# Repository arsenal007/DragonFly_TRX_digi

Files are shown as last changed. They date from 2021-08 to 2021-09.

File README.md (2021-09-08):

# DragonFly_TRX_digi
DragonFly 7Mhz HF transceiver for DIGITAL Modes

Assambly:
 1) Band pass filter
 2) QER Crystal filter
 3) MCU VFO part, first of all RX/TX for RX and TX path power supplay
  3.1 also VFO/BFO is important, using frequency counter to calibrate. BFO use 2µA
  
 4) Q1/Q6 setup current about 20mA
 5) mount 78L06(U13) and mixer, check voltage
 6)

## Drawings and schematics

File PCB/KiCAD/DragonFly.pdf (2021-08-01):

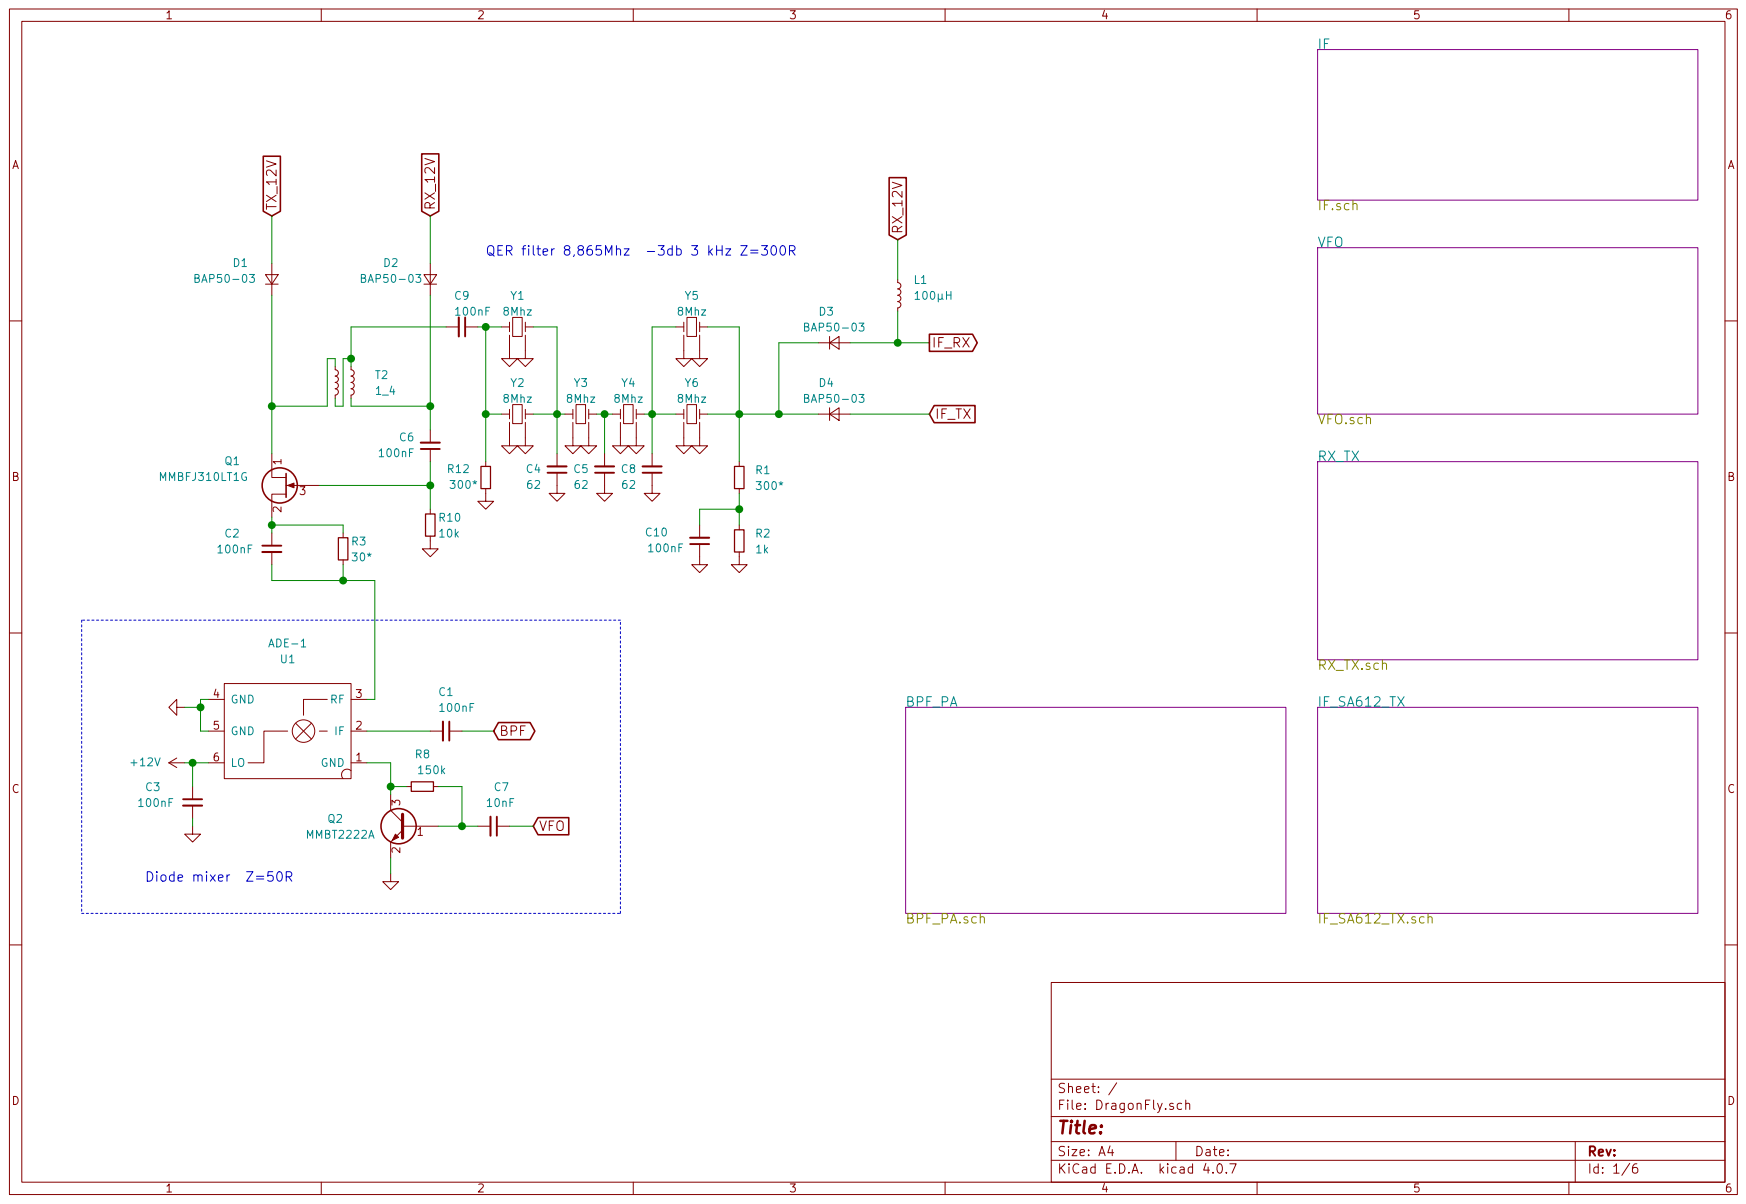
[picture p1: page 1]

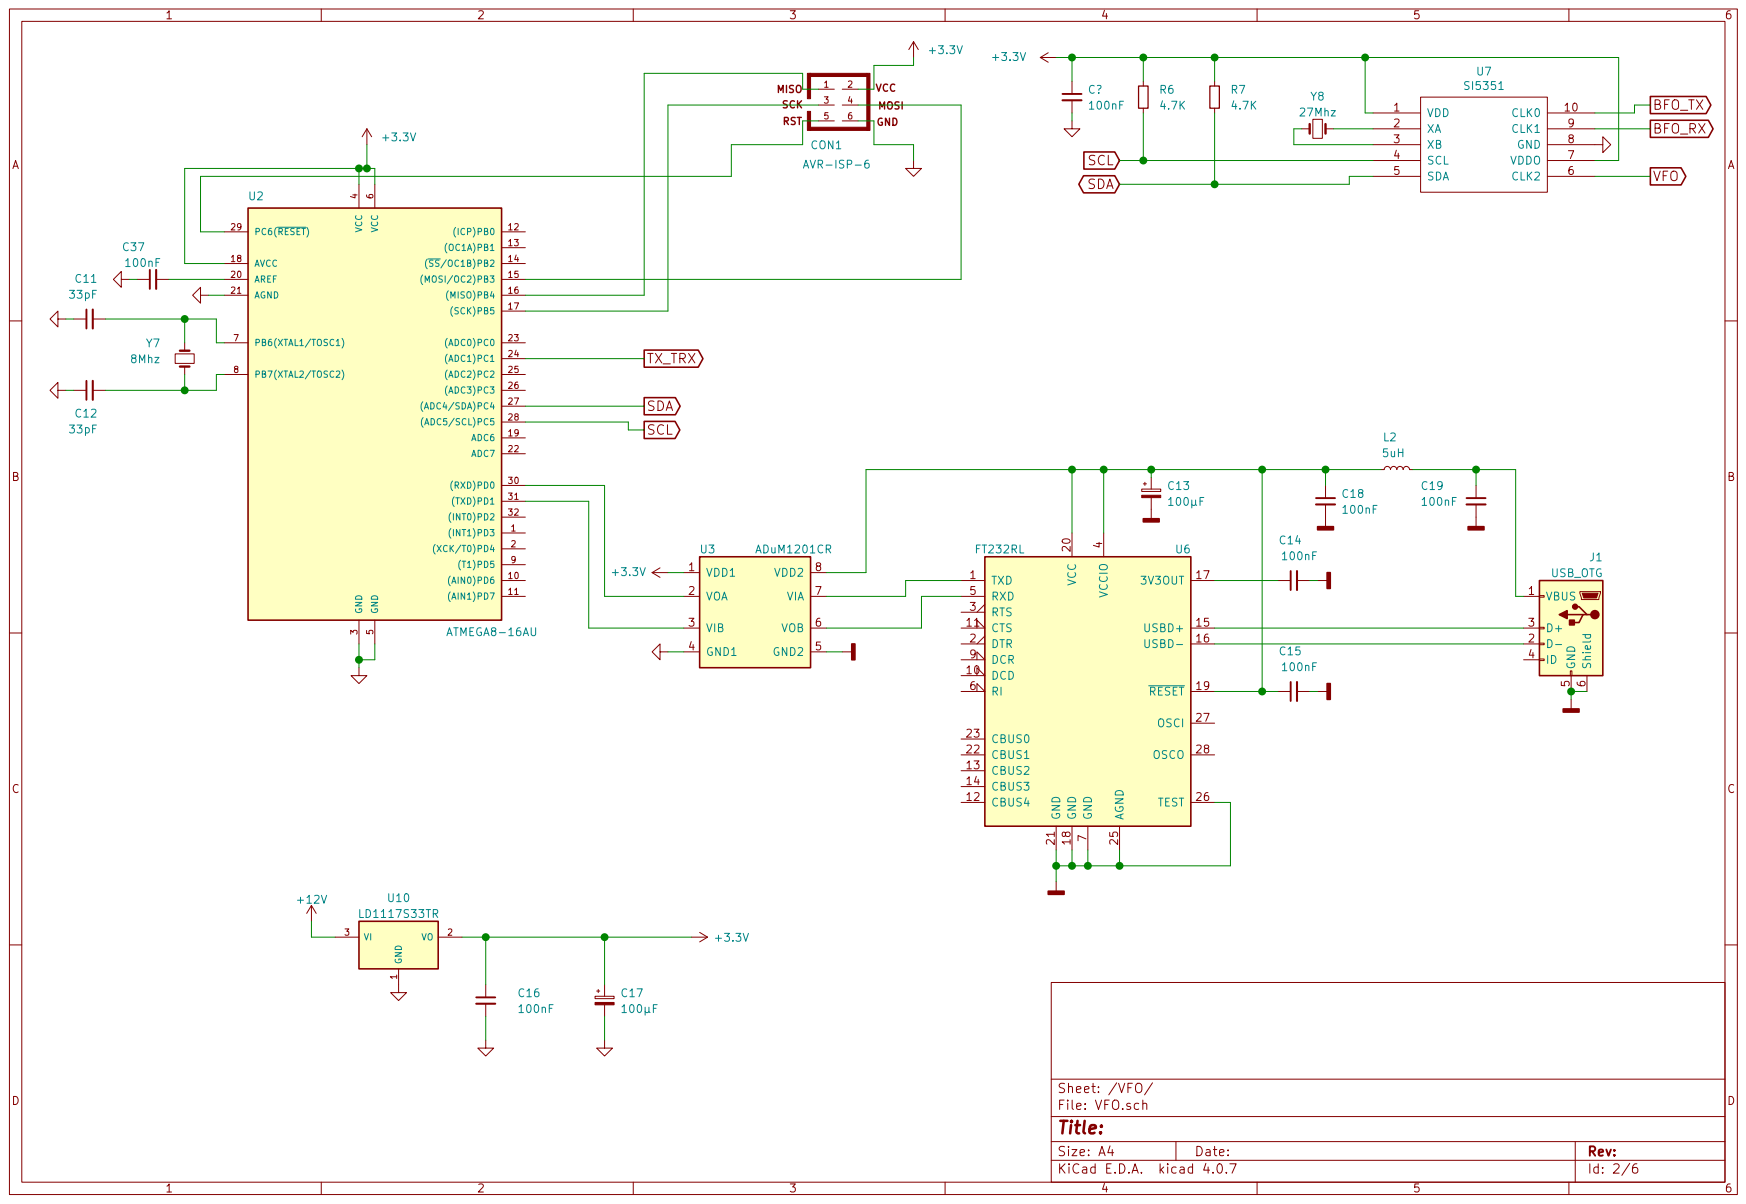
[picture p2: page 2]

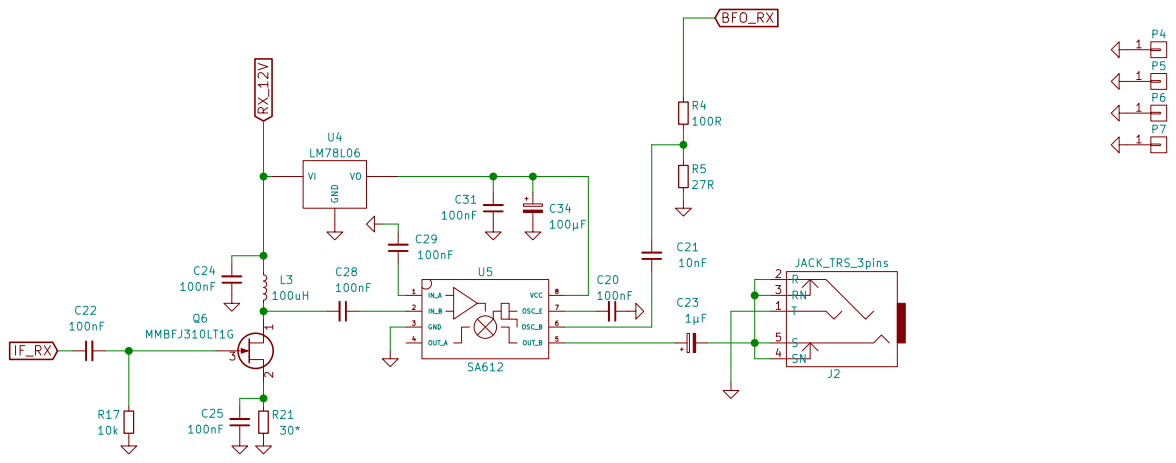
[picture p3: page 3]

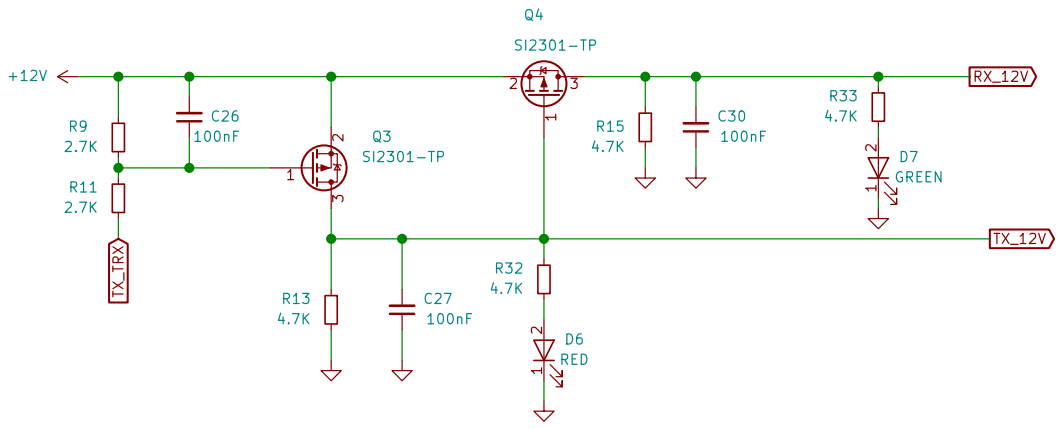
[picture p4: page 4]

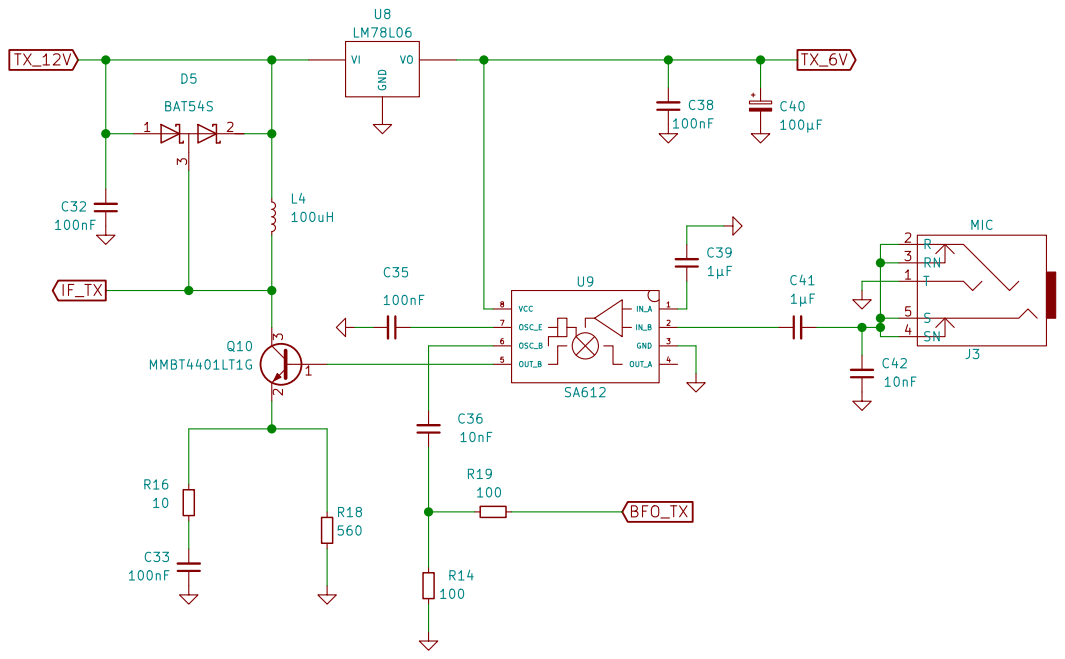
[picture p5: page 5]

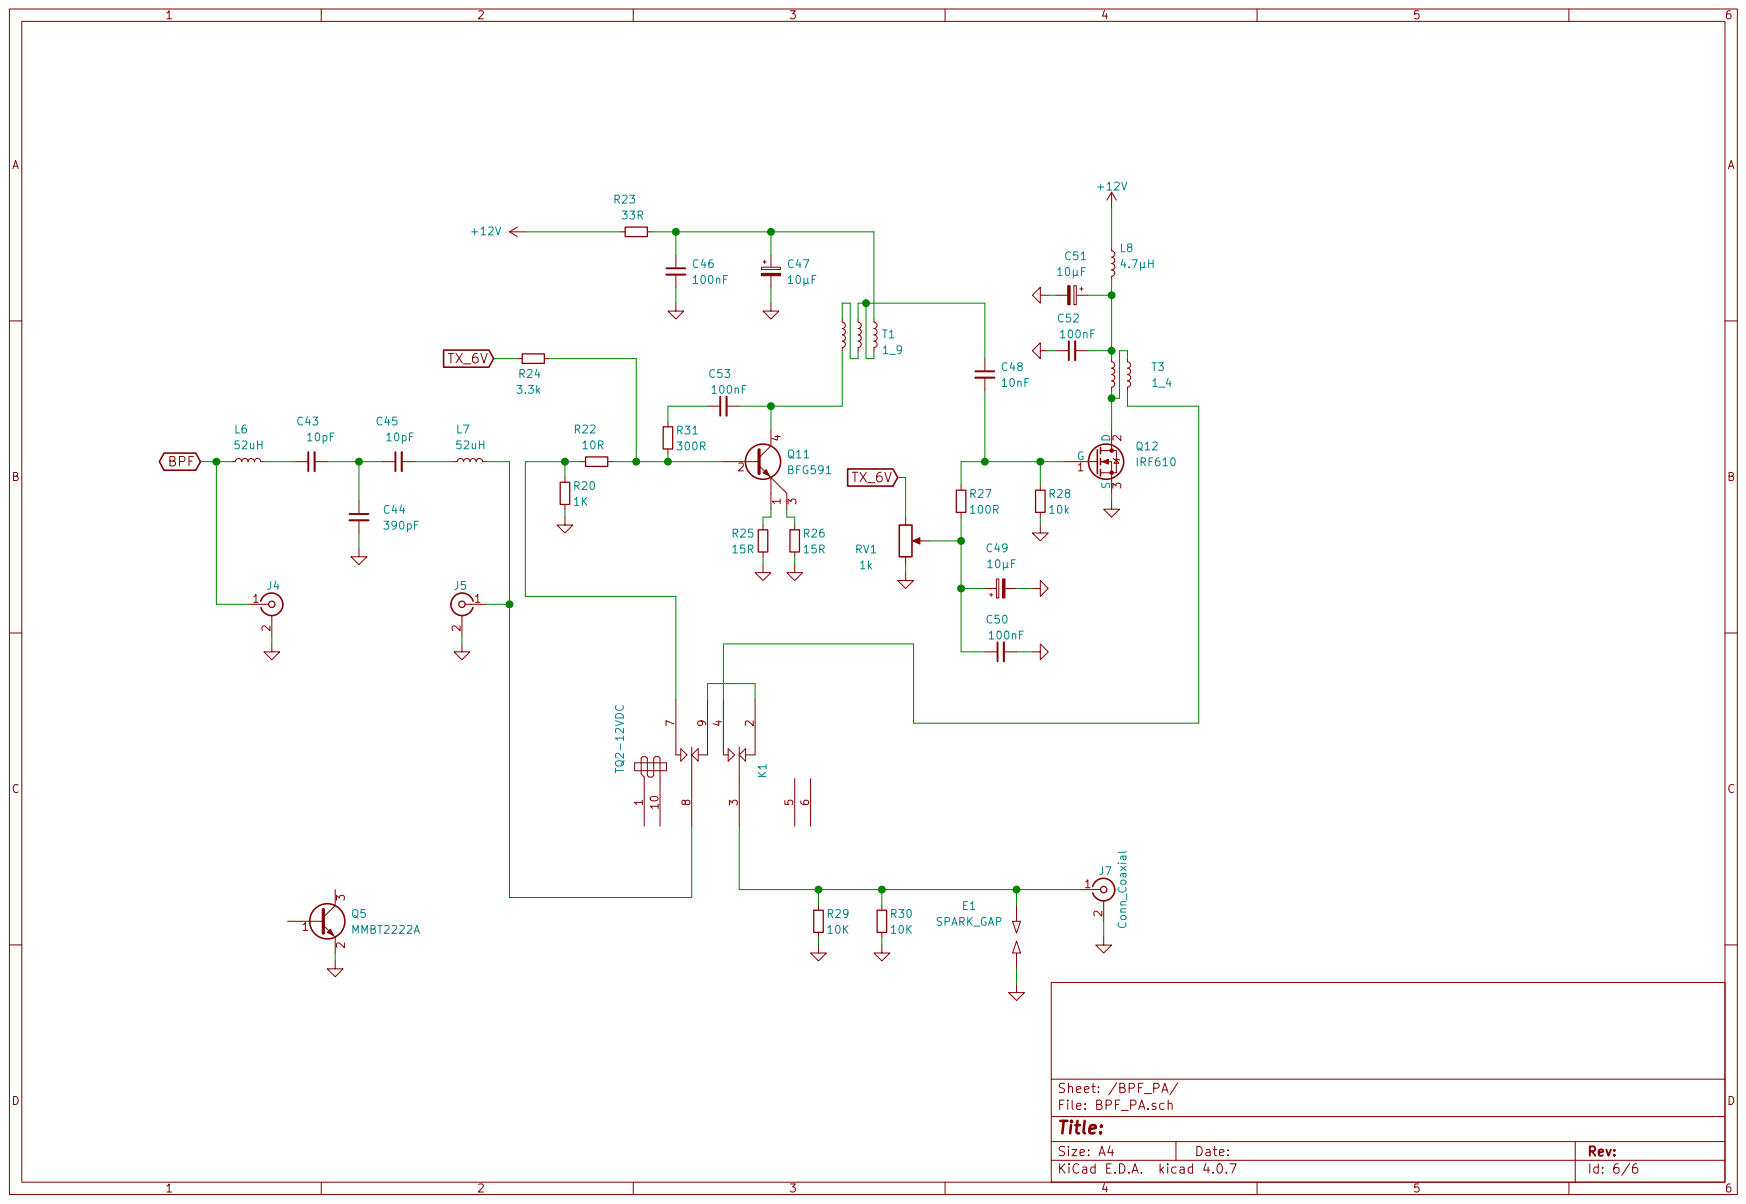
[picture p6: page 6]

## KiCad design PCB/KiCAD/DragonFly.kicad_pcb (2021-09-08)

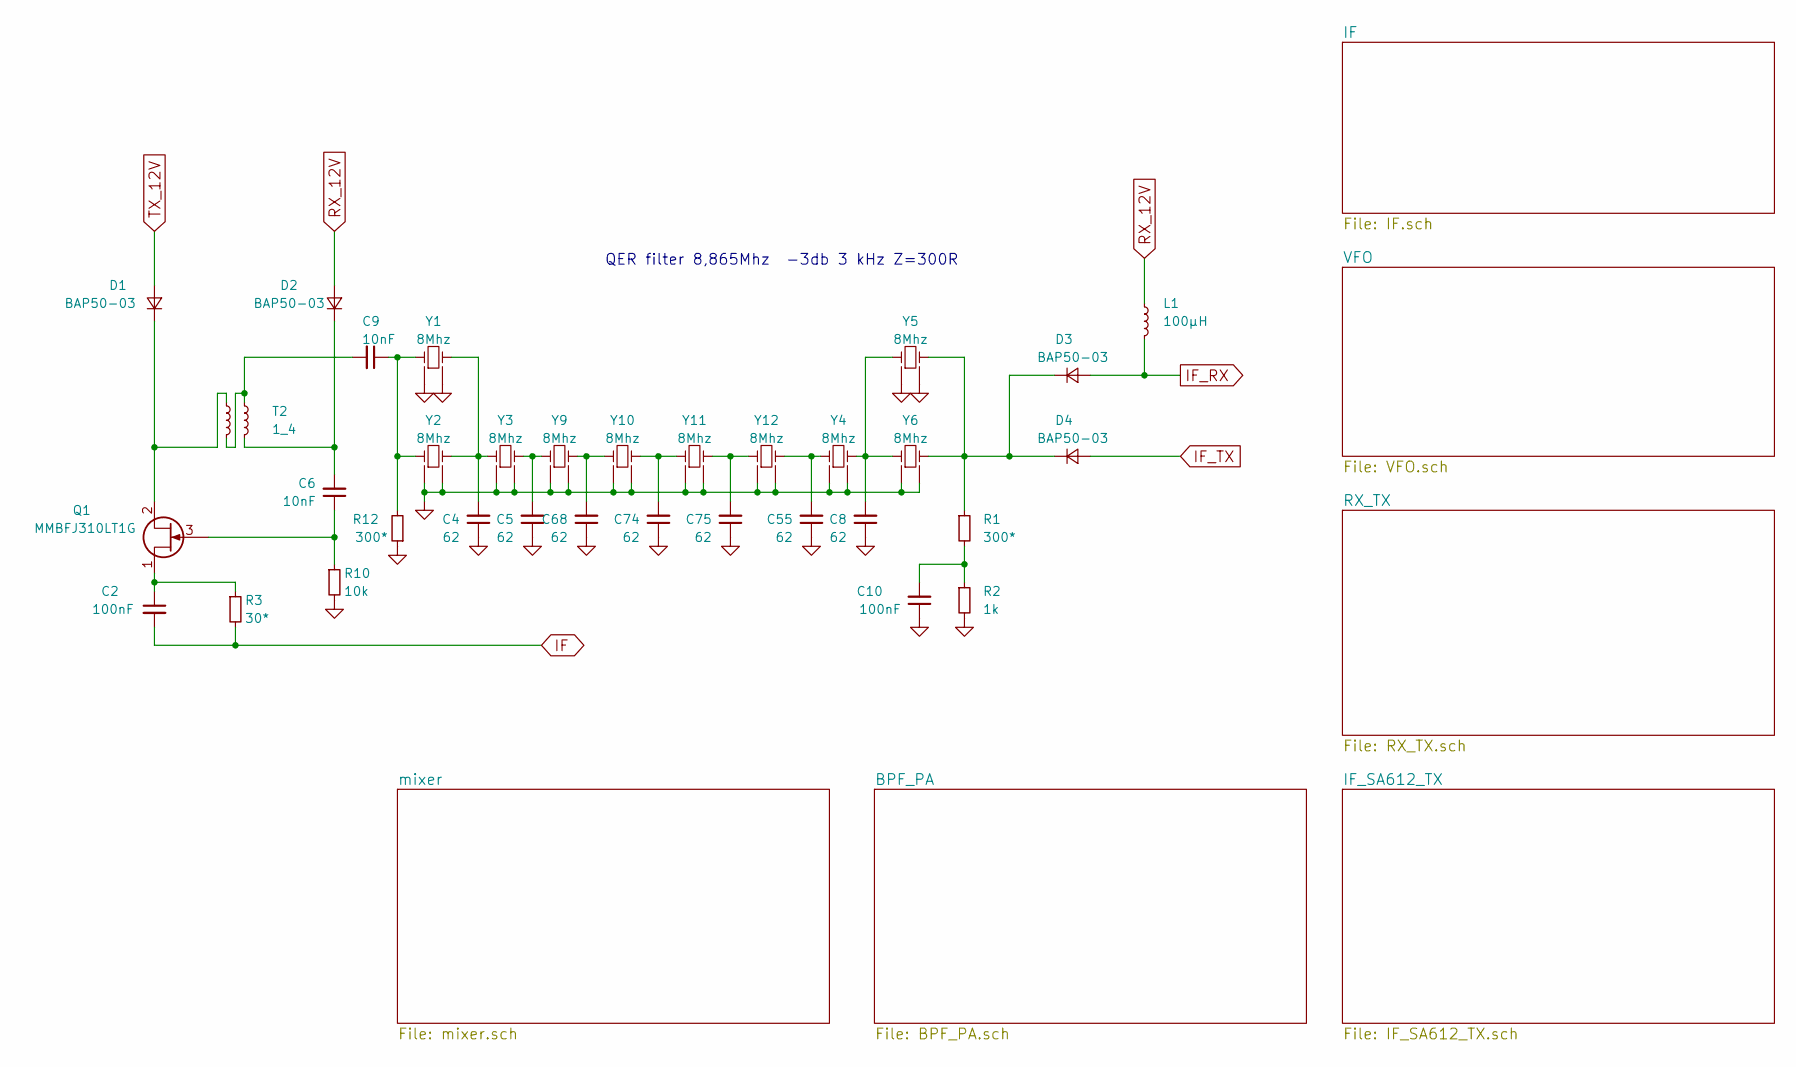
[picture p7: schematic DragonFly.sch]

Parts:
C2: 100nF; C_0603_HandSoldering
C4, C5, C8, C55, C68, C74, C75: 62; C_0805
C6, C9: 10nF; C_0603_HandSoldering
C10: 100nF; C_1206_0603
D1, D2, D3, D4: BAP50-03; D_SOD-323_HandSoldering
L1: 100µH; R_Axial_DIN0309_L9.0mm_D3.2mm_P2.54mm_Vertical
Q1: MMBFJ310LT1G; SOT-23
R1, R12: 300*; R_1206_0603
R2: 1k; R_1206_0603
R3: 30*; R_1206_0603
R10: 10k; R_0603_HandSoldering
T2: 1_4; TF14
Y1, Y2, Y3, Y4, Y5, Y6, Y9, Y10, Y11, Y12: 8Mhz; Crystal_HC49-U_Vertical

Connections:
GND: C4.1, C5.1, C8.1, C10.1, C55.1, C68.1, C74.1, C75.1, R2.2, R10.2, R12.1, Y1.3 (GND), Y1.4 (GND), Y2.3 (GND), Y2.4 (GND), Y3.3 (GND), Y3.4 (GND), Y4.3 (GND), Y4.4 (GND), Y5.3 (GND), Y5.4 (GND), Y6.3 (GND), Y6.4 (GND), Y9.3 (GND), Y9.4 (GND), Y10.3 (GND), Y10.4 (GND), Y11.3 (GND), Y11.4 (GND), Y12.3 (GND), Y12.4 (GND); also elsewhere on the board
IF: C2.2, R3.2; also elsewhere on the board
IF_RX: D3.2 (A), L1.2; also elsewhere on the board
IF_TX: D4.2 (A); also elsewhere on the board
unnamed: C2.1, Q1.1 (D), R3.1
unnamed: C4.2, Y1.2, Y2.2, Y3.1
unnamed: C5.2, Y3.2, Y9.1
unnamed: C6.1, Q1.3 (G), R10.1
unnamed: C6.2, D2.1 (K), T2.4
unnamed: C8.2, Y4.2, Y5.1, Y6.1
unnamed: C9.1, R12.2, Y1.1, Y2.1
unnamed: C9.2, T2.2, T2.3
unnamed: C10.2, R1.2, R2.1
unnamed: C55.2, Y4.1, Y12.2
unnamed: C68.2, Y9.2, Y10.1
unnamed: C74.2, Y10.2, Y11.1
unnamed: C75.2, Y11.2, Y12.1
unnamed: D1.1 (K), Q1.2 (S), T2.1
unnamed: D3.1 (K), D4.1 (K), R1.1, Y5.2, Y6.2
RX_12V: D2.2 (A), L1.1; also elsewhere on the board
TX_12V: D1.2 (A); also elsewhere on the board

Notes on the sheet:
QER filter 8,865Mhz -3db 3 kHz Z=300R

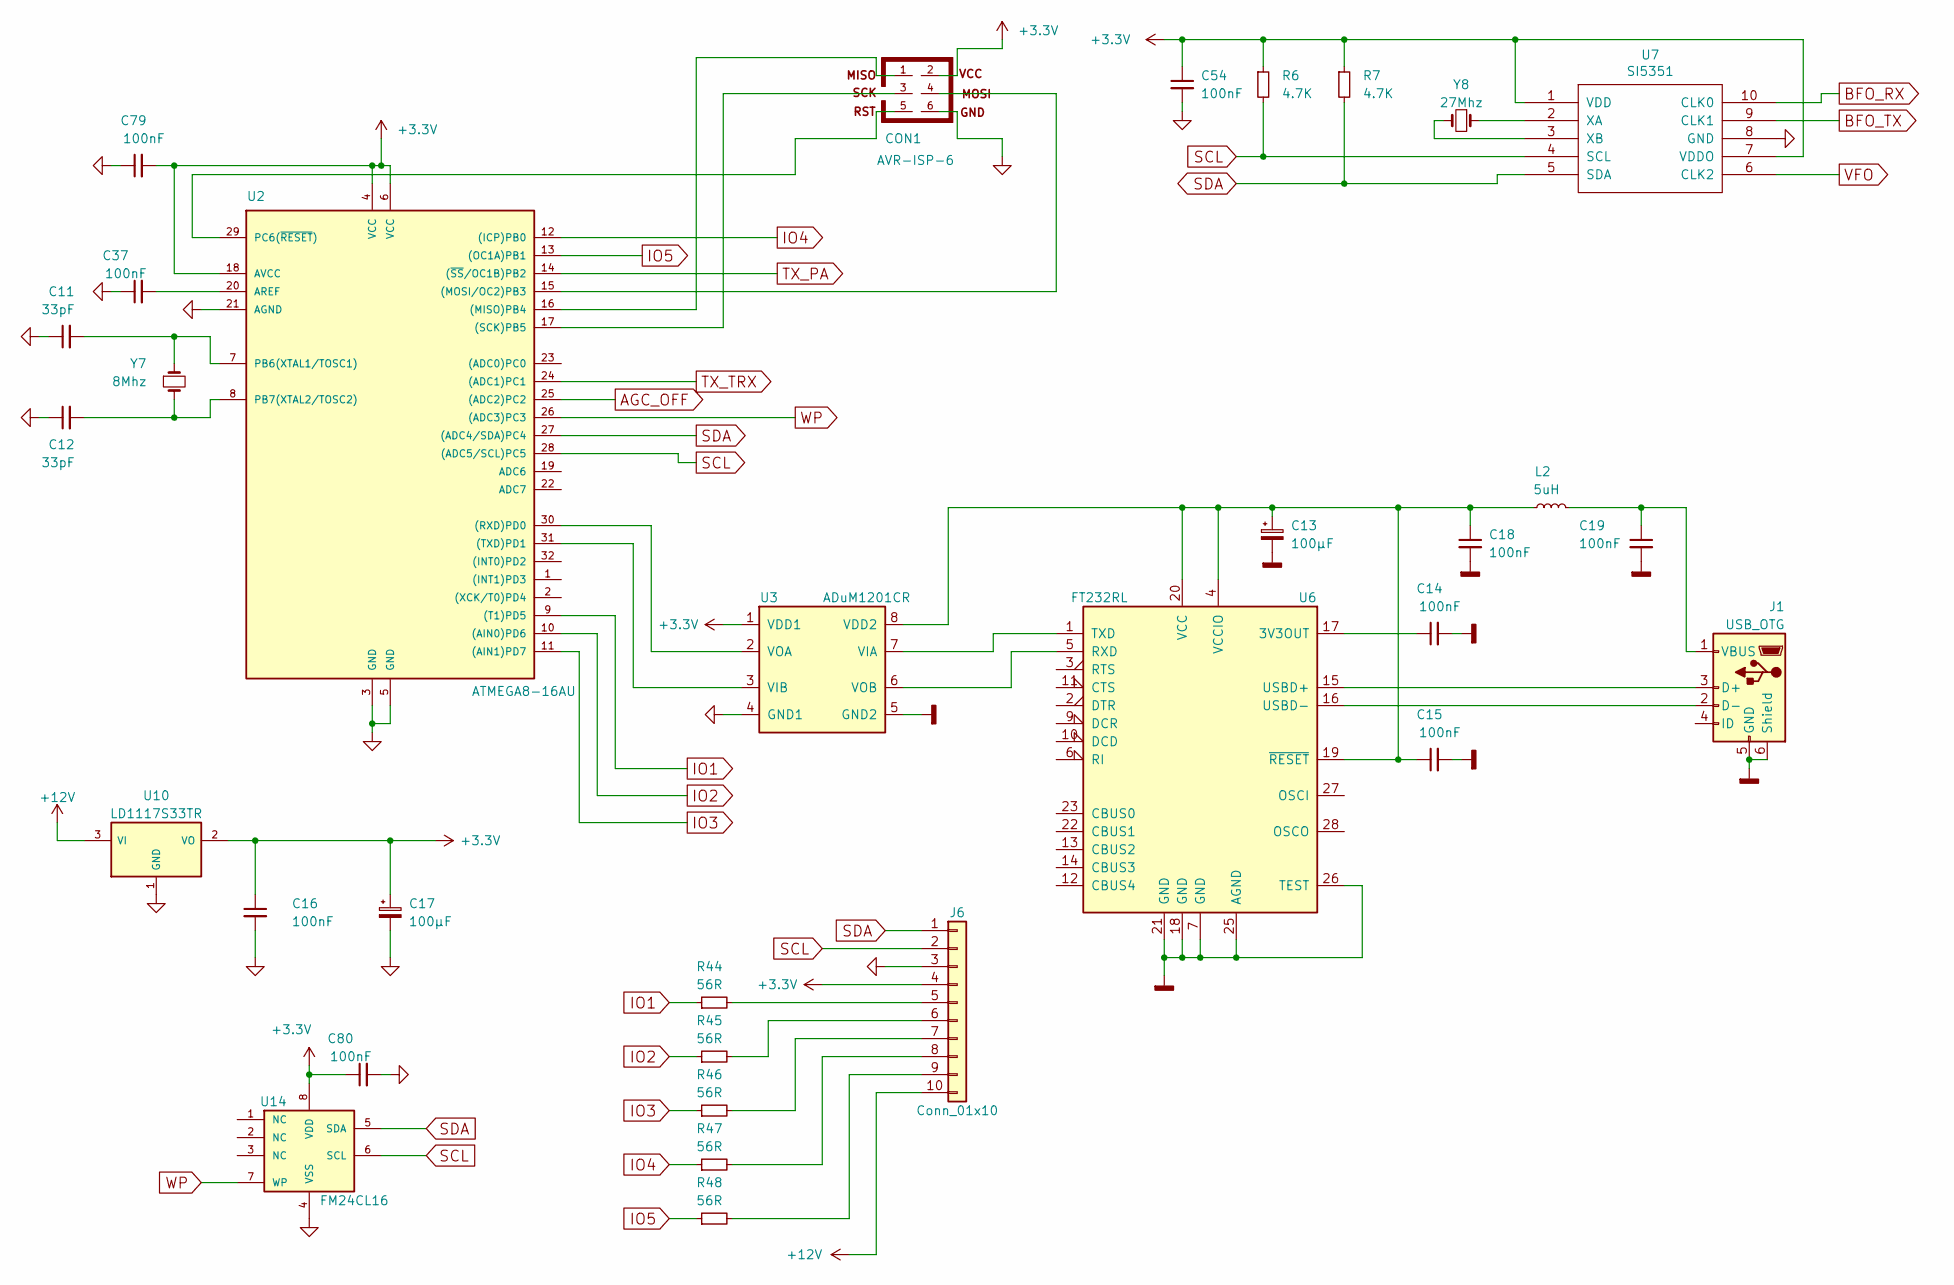
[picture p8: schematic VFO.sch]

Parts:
C11, C12: 33pF; C_1206_0603
C13, C17: 100µF; CP_Radial_D6.3mm_P2.50mm
C14, C15, C18, C19: 100nF; C_0603_HandSoldering
C16, C37, C54, C79, C80: 100nF; C_1206_0603
CON1: AVR-ISP-6; Pin_Header_Straight_2x03_Pitch2.54mm
J1: USB_OTG; USB_Mini-B
J6: Conn_01x10; Pin_Header_Straight_1x10_Pitch2.54mm
L2: 5uH; R_Axial_DIN0309_L9.0mm_D3.2mm_P2.54mm_Vertical
R6, R7: 4.7K; R_1206_0603
R44, R45, R46, R47, R48: 56R; R_0603_HandSoldering
U2: ATMEGA8-16AU; TQFP-32_7x7mm_Pitch0.8mm
U3: ADuM1201CR; SOIC-8_3.9x4.9mm_Pitch1.27mm
U6: FT232RL; SSOP-28_5.3x10.2mm_Pitch0.65mm
U7: SI5351; MSOP-10_3x3mm_Pitch0.5mm
U10: LD1117S33TR; SOT-223
U14: FM24CL16; SOIC-8_3.9x4.9mm_Pitch1.27mm
Y7: 8Mhz; Crystal_HC49-4H_Vertical
Y8: 27Mhz; Crystal_SMD_HC49-SD

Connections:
+3V3: C16.1, C17.1, C54.1, C79.2, C80.1, CON1.2, J6.4, R6.1, R7.1, U2.4 (VCC), U2.6 (VCC), U2.18 (AVCC), U3.1 (VDD1), U7.1 (VDD), U7.7 (VDDO), U10.2 (VO), U14.8 (VDD)
+12V: J6.10, U10.3 (VI); also elsewhere on the board
AGC_OFF: U2.25 ((ADC2)PC2); also elsewhere on the board
BFO_RX: U7.10 (CLK0); also elsewhere on the board
BFO_TX: U7.9 (CLK1); also elsewhere on the board
GND: C11.1, C12.1, C16.2, C17.2, C37.1, C54.2, C79.1, C80.2, CON1.6, J6.3, U2.3 (GND), U2.5 (GND), U2.21 (AGND), U3.4 (GND1), U7.8 (GND), U10.1 (GND), U14.4 (VSS); also elsewhere on the board
GNDD: C13.2, C14.2, C15.2, C18.2, C19.2, J1.5 (GND), J1.6 (Shield), U3.5 (GND2), U6.7 (GND), U6.18 (GND), U6.21 (GND), U6.25 (AGND), U6.26 (TEST)
IO1: R44.1, U2.9 ((T1)PD5)
IO2: R45.1, U2.10 ((AIN0)PD6)
IO3: R46.1, U2.11 ((AIN1)PD7)
IO4: R47.1, U2.12 ((ICP)PB0)
IO5: R48.1, U2.13 ((OC1A)PB1)
unnamed: C11.2, U2.7 (PB6(XTAL1/TOSC1)), Y7.1
unnamed: C12.2, U2.8 (PB7(XTAL2/TOSC2)), Y7.2
unnamed: C13.1, C15.1, C18.1, L2.1, U3.8 (VDD2), U6.4 (VCCIO), U6.19 (~RESET~), U6.20 (VCC)
unnamed: C14.1, U6.17 (3V3OUT)
unnamed: C19.1, J1.1 (VBUS), L2.2
unnamed: C37.2, U2.20 (AREF)
unnamed: CON1.1, U2.16 ((MISO)PB4)
unnamed: CON1.3, U2.17 ((SCK)PB5)
unnamed: CON1.4, U2.15 ((MOSI/OC2)PB3)
unnamed: CON1.5, U2.29 (PC6(~RESET~))
unnamed: J1.2 (D-), U6.16 (USBD-)
unnamed: J1.3 (D+), U6.15 (USBD+)
unnamed: J6.5, R44.2
unnamed: J6.6, R45.2
unnamed: J6.7, R46.2
unnamed: J6.8, R47.2
unnamed: J6.9, R48.2
unnamed: U2.30 ((RXD)PD0), U3.2 (VOA)
unnamed: U2.31 ((TXD)PD1), U3.3 (VIB)
unnamed: U3.6 (VOB), U6.5 (RXD)
unnamed: U3.7 (VIA), U6.1 (TXD)
unnamed: U7.2 (XA), Y8.1
unnamed: U7.3 (XB), Y8.2
SCL: J6.2, R6.2, U2.28 ((ADC5/SCL)PC5), U7.4 (SCL), U14.6 (SCL)
SDA: J6.1, R7.2, U2.27 ((ADC4/SDA)PC4), U7.5 (SDA), U14.5 (SDA)
TX_PA: U2.14 ((~SS~/OC1B)PB2); also elsewhere on the board
TX_TRX: U2.24 ((ADC1)PC1); also elsewhere on the board
VFO: U7.6 (CLK2); also elsewhere on the board
WP: U2.26 ((ADC3)PC3), U14.7 (WP)

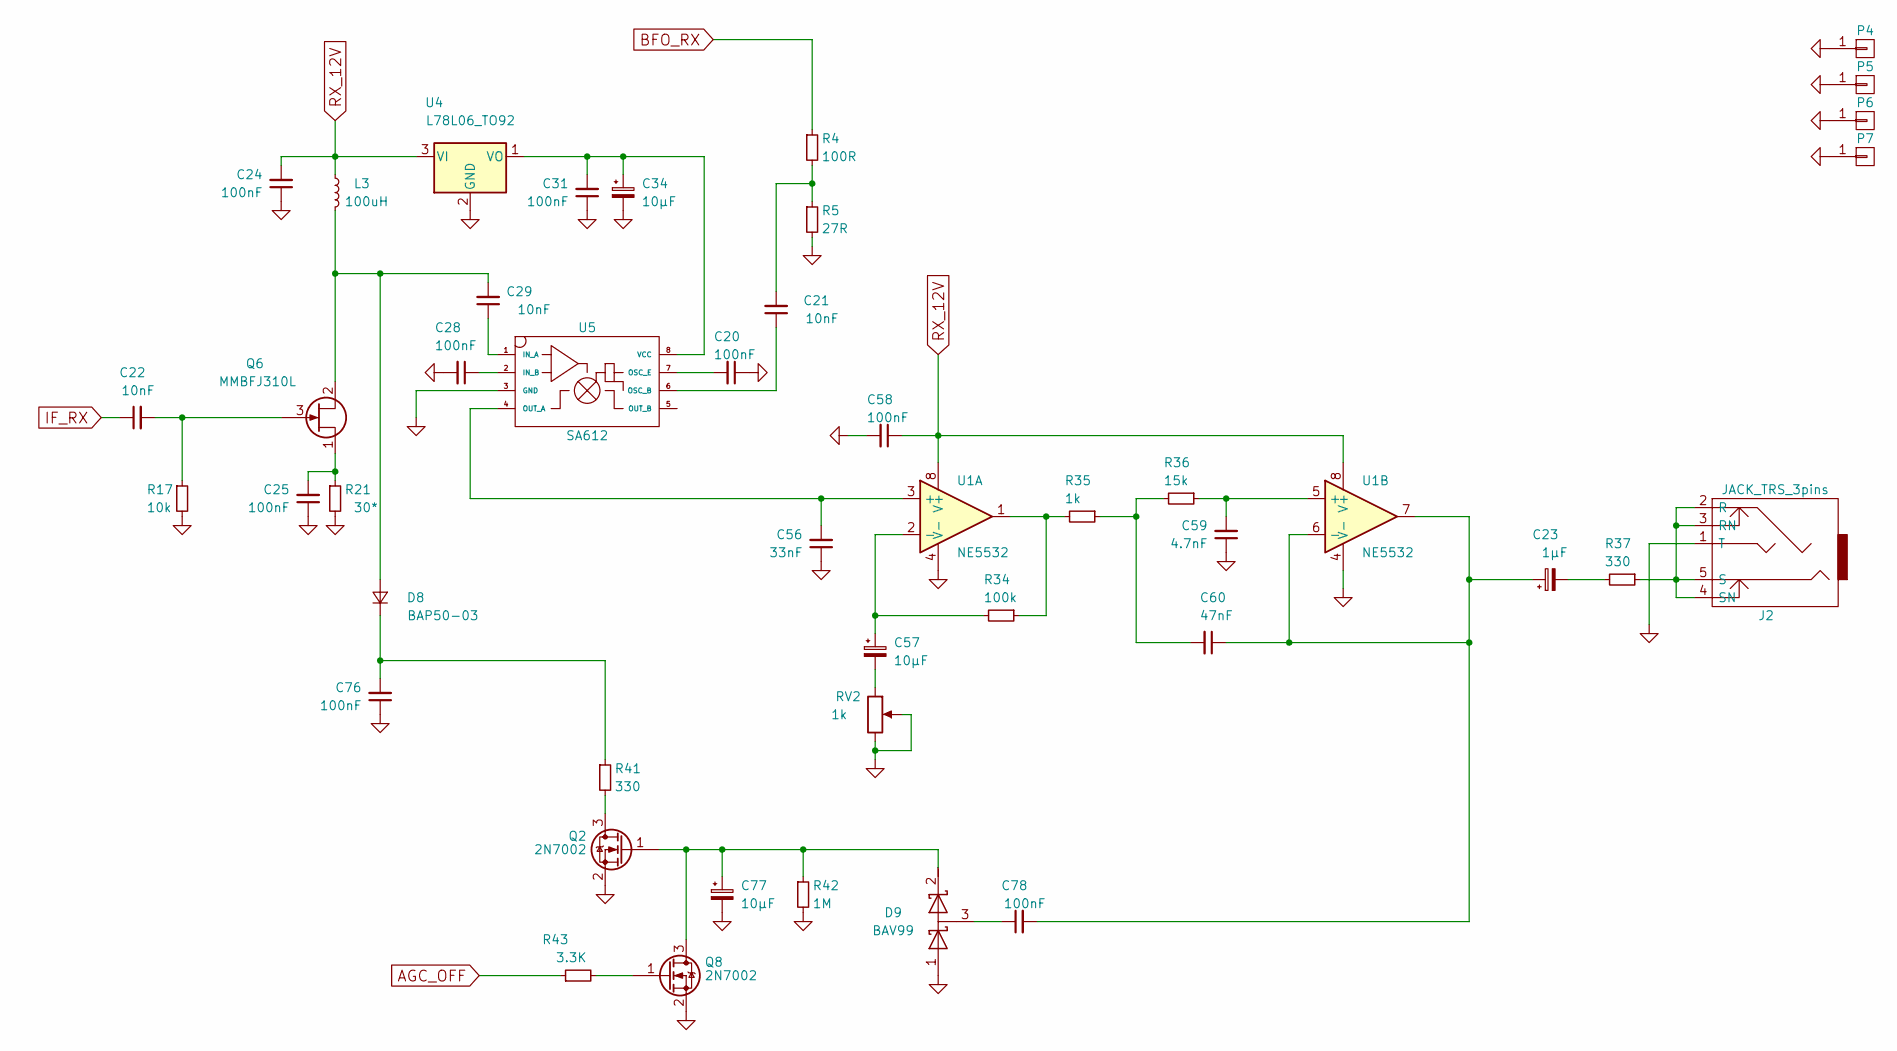
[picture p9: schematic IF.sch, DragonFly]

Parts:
C20, C24, C25, C28, C31, C58, C76, C78: 100nF; C_1206_0603
C21, C22, C29: 10nF; C_0603_HandSoldering
C23: 1µF; CP_Radial_D4.0mm_P2.00mm
C34, C57, C77: 10µF; CP_Radial_D4.0mm_P2.00mm
C56: 33nF; C_1206_0603
C59: 4.7nF; C_0603_HandSoldering
C60: 47nF; C_1206_0603
D8: BAP50-03; D_SOD-323_HandSoldering
D9: BAV99; SOT-23
J2: JACK_TRS_3pins; audio_jack_3_5mm_PJ307
L3: 100uH; R_Axial_DIN0309_L9.0mm_D3.2mm_P2.54mm_Vertical
P4, P5, P6, P7: CONN_01X01; MountingHole_3.2mm_M3_DIN965_Pad
Q2, Q8: 2N7002; SOT-23
Q6: MMBFJ310L; SOT-23
R4: 100R; R_1206_0603
R5: 27R; R_1206_0603
R17: 10k; R_1206_0603
R21: 30*; R_1206_0603
R34: 100k; R_1206_0603
R35: 1k; R_0603_HandSoldering
R36: 15k; R_0603_HandSoldering
R37, R41: 330; R_1206_0603
R42: 1M; R_1206_0603
R43: 3.3K; R_1206_0603
RV2: 1k; Potentiometer_Trimmer_Piher_PT-6v_Horizontal
U1: NE5532; SOIC-8_3.9x4.9mm_Pitch1.27mm
U4: L78L06_TO92; TO-92_Molded_Wide_Oval
U5: SA612; SOIC-8_3.9x4.9mm_Pitch1.27mm

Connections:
AGC_OFF: R43.1; also elsewhere on the board
BFO_RX: R4.1; also elsewhere on the board
GND: C20.1, C24.1, C25.1, C28.2, C31.1, C34.2, C56.1, C58.2, C59.1, C76.1, C77.2, D9.1 (A), J2.1 (T), P4.1, P5.1, P6.1, P7.1, Q2.2 (S), Q8.2 (S), R5.2, R17.2, R21.2, R42.2, RV2.2, RV2.3, U1.4 (V-), U4.2 (GND), U5.3 (GND); also elsewhere on the board
IF_RX: C22.1; also elsewhere on the board
unnamed: C20.2, U5.7 (OSC_E)
unnamed: C21.1, U5.6 (OSC_B)
unnamed: C21.2, R4.2, R5.1
unnamed: C22.2, Q6.3 (G), R17.1
unnamed: C23.1, C60.1, C78.2, U1.6 (-), U1.7
unnamed: C23.2, R37.2
unnamed: C25.2, Q6.1 (D), R21.1
unnamed: C28.1, U5.2 (IN_B)
unnamed: C29.1, U5.1 (IN_A)
unnamed: C29.2, D8.2 (A), L3.2, Q6.2 (S)
unnamed: C31.2, C34.1, U4.1 (VO), U5.8 (VCC)
unnamed: C56.2, U1.3 (+), U5.4 (OUT_A)
unnamed: C57.1, R34.2, U1.2 (-)
unnamed: C57.2, RV2.1
unnamed: C59.2, R36.1, U1.5 (+)
unnamed: C60.2, R35.1, R36.2
unnamed: C76.2, D8.1 (K), R41.1
unnamed: C77.1, D9.2 (K), Q2.1 (G), Q8.3 (D), R42.1
unnamed: C78.1, D9.3 (common)
unnamed: J2.2 (R), J2.3 (RN), J2.4 (SN), J2.5 (S), R37.1
unnamed: Q2.3 (D), R41.2
unnamed: Q8.1 (G), R43.2
unnamed: R34.1, R35.2, U1.1
RX_12V: C24.2, C58.1, L3.1, U1.8 (V+), U4.3 (VI); also elsewhere on the board

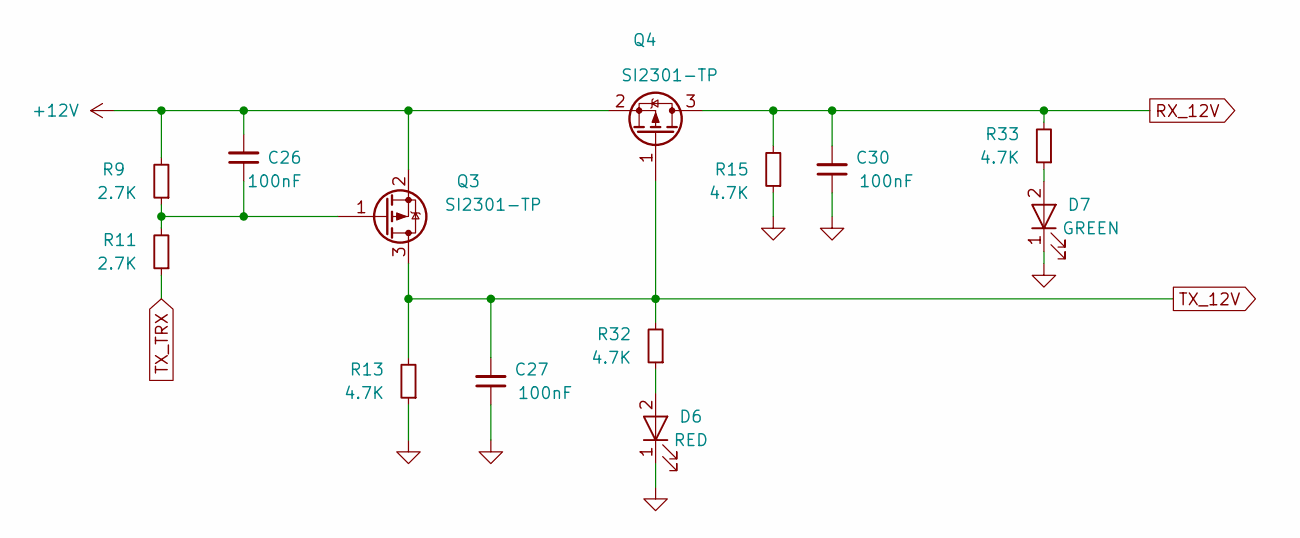
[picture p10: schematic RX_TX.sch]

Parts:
C26, C27, C30: 100nF; C_1206_0603
D6: RED; LED_D3.0mm_Horizontal_O3.81mm_Z10.0mm
D7: GREEN; LED_D3.0mm_Horizontal_O3.81mm_Z10.0mm
Q3, Q4: SI2301-TP; SOT-23
R9, R11: 2.7K; R_1206_0603
R13, R15, R32, R33: 4.7K; R_1206_0603

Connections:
+12V: C26.2, Q3.2 (S), Q4.2 (S), R9.2; also elsewhere on the board
GND: C27.1, C30.1, D6.1 (K), D7.1 (K), R13.1, R15.1; also elsewhere on the board
unnamed: C26.1, Q3.1 (G), R9.1, R11.2
unnamed: D6.2 (A), R32.1
unnamed: D7.2 (A), R33.1
RX_12V: C30.2, Q4.3 (D), R15.2, R33.2; also elsewhere on the board
TX_12V: C27.2, Q3.3 (D), Q4.1 (G), R13.2, R32.2; also elsewhere on the board
TX_TRX: R11.1; also elsewhere on the board

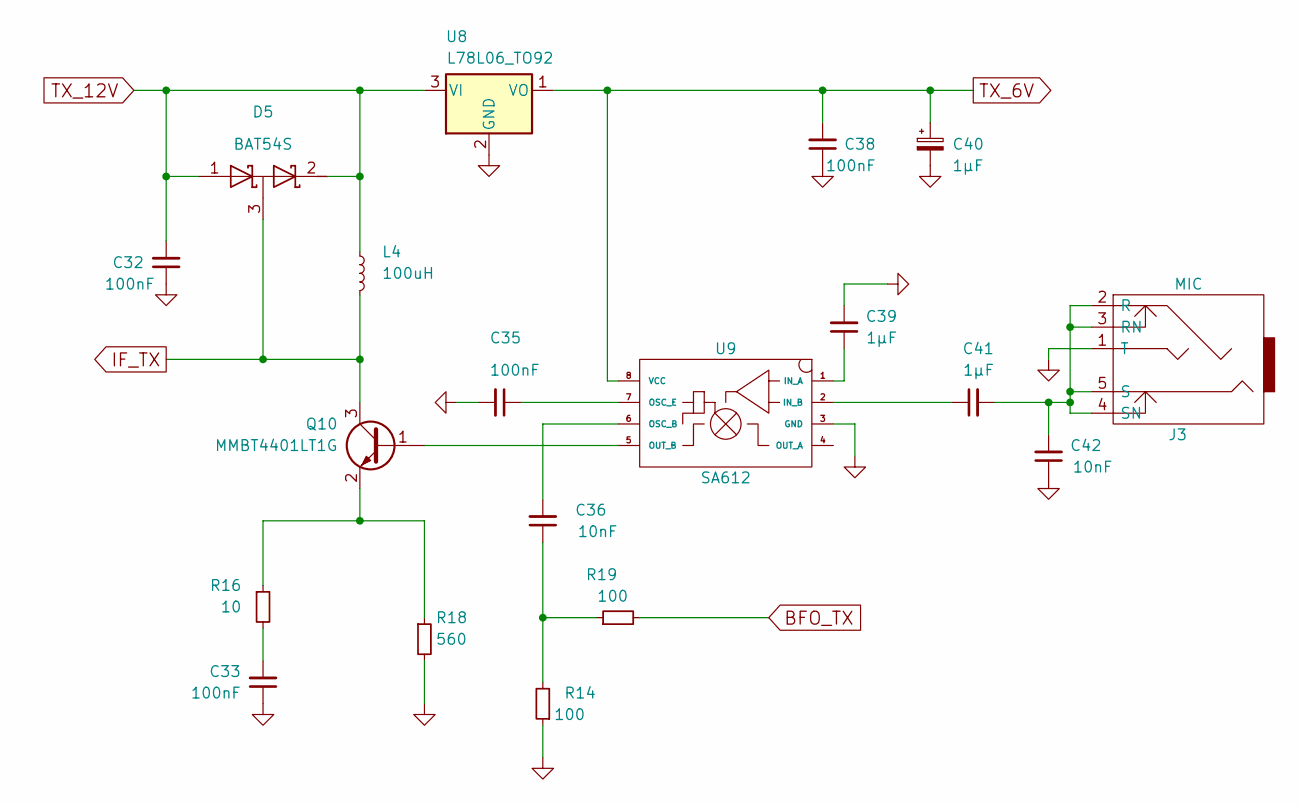
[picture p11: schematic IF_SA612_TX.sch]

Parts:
C32, C33, C35, C38: 100nF; C_1206_0603
C36, C42: 10nF; C_0603_HandSoldering
C39, C41: 1µF; C_1206_0603
C40: 1µF; CP_Radial_D4.0mm_P2.00mm
D5: BAT54S; SOT-23
J3: MIC; audio_jack_3_5mm_PJ307
L4: 100uH; R_Axial_DIN0309_L9.0mm_D3.2mm_P2.54mm_Vertical
Q10: MMBT4401LT1G; SOT-23
R14, R19: 100; R_1206_0603
R16: 10; R_1206_0603
R18: 560; R_1206_0603
U8: L78L06_TO92; TO-92_Molded_Wide_Oval
U9: SA612; SOIC-8_3.9x4.9mm_Pitch1.27mm

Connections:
BFO_TX: R19.2; also elsewhere on the board
GND: C32.1, C33.1, C35.2, C38.1, C39.2, C40.2, C42.1, J3.1 (T), R14.1, R18.2, U8.2 (GND), U9.3 (GND); also elsewhere on the board
IF_TX: D5.3 (common), L4.2, Q10.3 (C); also elsewhere on the board
unnamed: C33.2, R16.2
unnamed: C35.1, U9.7 (OSC_E)
unnamed: C36.1, R14.2, R19.1
unnamed: C36.2, U9.6 (OSC_B)
unnamed: C39.1, U9.1 (IN_A)
unnamed: C41.1, U9.2 (IN_B)
unnamed: C41.2, C42.2, J3.2 (R), J3.3 (RN), J3.4 (SN), J3.5 (S)
unnamed: Q10.1 (B), U9.5 (OUT_B)
unnamed: Q10.2 (E), R16.1, R18.1
TX_6V: C38.2, C40.1, U8.1 (VO), U9.8 (VCC); also elsewhere on the board
TX_12V: C32.2, D5.1 (A), D5.2 (K), L4.1, U8.3 (VI); also elsewhere on the board

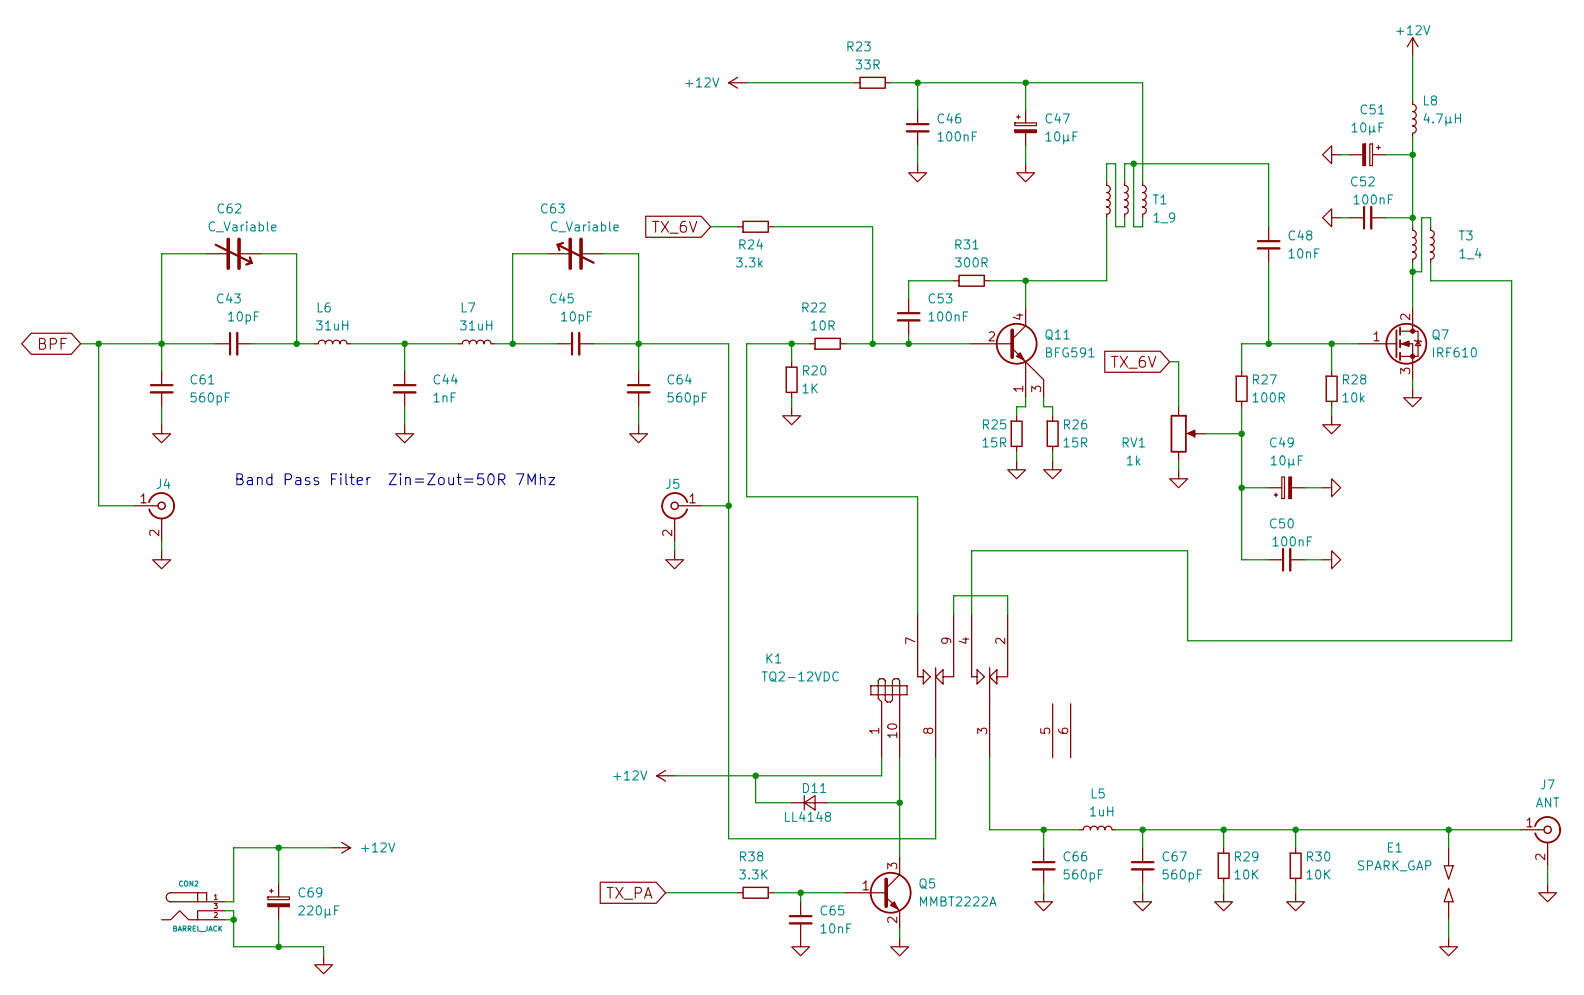
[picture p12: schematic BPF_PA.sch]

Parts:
C43, C45: 10pF; C_1206_0603
C44: 1nF; C_1206_0603
C46, C50, C52, C53: 100nF; C_1206_0603
C47, C49, C51: 10µF; CP_Radial_D4.0mm_P2.00mm
C48, C65: 10nF; C_0603_HandSoldering
C61, C64, C66, C67: 560pF; C_1206_0603
C62, C63: C_Variable; C_Trimmer_Voltronics_JZ
C69: 220µF; CP_Radial_D6.3mm_P2.50mm
CON2: BARREL_JACK
D11: LL4148; MiniMELF_Standard
E1: SPARK_GAP; Resistor_Vertical_RM5mm
J4, J5: Conn_Coaxial; U.FL_Molex_MCRF_73412-0110_Vertical
J7: ANT; SMA_THT_Jack_Straight
K1: TQ2-12VDC; Relay_DPDT_FRT5
L5: 1uH; Choke_Toroid_5x10mm_Vertical
L6, L7: 31uH; Choke_Toroid_5x10mm_Vertical
L8: 4.7µH; Choke_CD54
Q5: MMBT2222A; SOT-23
Q7: IRF610; TO-220_Neutral123_Horizontal_LargePads_BigHole
Q11: BFG591; SOT-223
R20: 1K; R_1206_0603
R22: 10R; R_1206_0603
R23: 33R; R_2512
R24: 3.3k; R_1206_0603
R25, R26: 15R; R_1206_0603
R27: 100R; R_1206_0603
R28: 10k; R_1206_0603
R29, R30: 10K; R_1206_0603
R31: 300R; R_1206_0603
R38: 3.3K; R_1206_0603
RV1: 1k; Potentiometer_Trimmer_Bourns_3296W
T1: 1_9; HF12
T3: 1_4; TRANSF1_4

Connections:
+12V: C69.1, CON2.1, D11.1 (K), K1.1 (+), L8.1, R23.1; also elsewhere on the board
BPF: C43.1, C61.1, C62.2, J4.1 (In); also elsewhere on the board
GND: C44.2, C46.2, C47.2, C49.2, C50.2, C51.2, C52.1, C61.2, C64.2, C65.2, C66.2, C67.2, C69.2, CON2.2, CON2.3, E1.2, J4.2 (Ext), J5.2 (Ext), J7.2 (Ext), Q5.2 (E), Q7.3 (S), R20.2, R25.2, R26.2, R28.2, R29.2, R30.2, RV1.3; also elsewhere on the board
unnamed: C43.2, C62.1, L6.1
unnamed: C44.1, L6.2, L7.1
unnamed: C45.1, C63.1, L7.2
unnamed: C45.2, C63.2, C64.1, J5.1 (In), K1.8 (C1)
unnamed: C46.1, C47.1, R23.2, T1.6
unnamed: C48.1, T1.4, T1.5
unnamed: C48.2, Q7.1 (G), R27.1, R28.1
unnamed: C49.1, C50.1, R27.2, RV1.2
unnamed: C51.1, C52.2, L8.2, T3.1
unnamed: C53.1, R31.1
unnamed: C53.2, Q11.2 (B), R22.2, R24.2
unnamed: C65.1, Q5.1 (B), R38.1
unnamed: C66.1, K1.3 (C2), L5.1
unnamed: C67.1, E1.1, J7.1 (In), L5.2, R29.1, R30.1
unnamed: D11.2 (A), K1.10 (-), Q5.3 (C)
unnamed: K1.2 (R2), K1.9 (R1)
unnamed: K1.4 (T2), T3.4
unnamed: K1.7 (T1), R20.1, R22.1
unnamed: Q7.2 (D), T3.2, T3.3
unnamed: Q11.1 (E), R25.1
unnamed: Q11.3 (E), R26.1
unnamed: Q11.4 (C), R31.2, T1.1
unnamed: T1.2, T1.3
TX_6V: R24.1, RV1.1; also elsewhere on the board
TX_PA: R38.2; also elsewhere on the board

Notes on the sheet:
Band Pass Filter Zin=Zout=50R 7Mhz

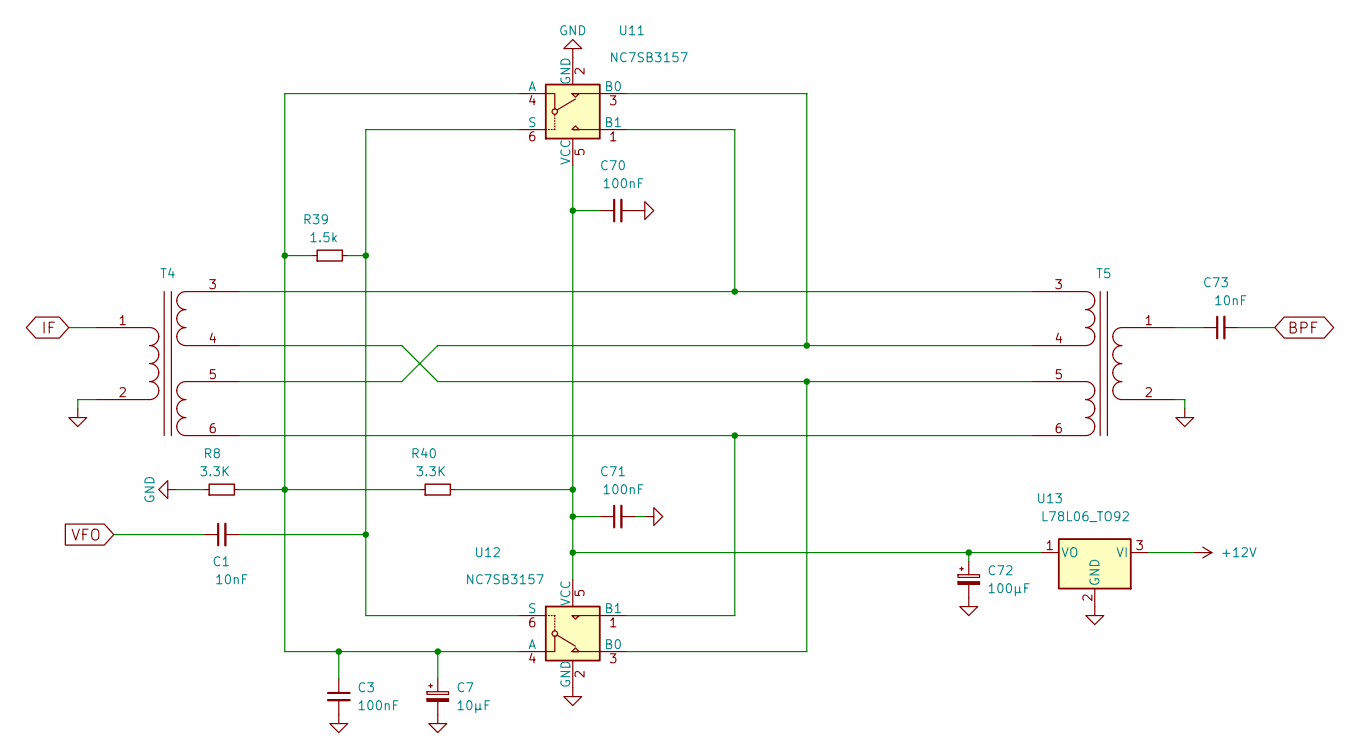
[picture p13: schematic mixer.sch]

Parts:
C1, C73: 10nF; C_0603_HandSoldering
C3, C70, C71: 100nF; C_1206_0603
C7: 10µF; CP_Radial_D4.0mm_P2.00mm
C72: 100µF; CP_Radial_D6.3mm_P2.50mm
R8, R40: 3.3K; R_1206_0603
R39: 1.5k; R_1206_0603
T4, T5: Transformer_1P_2S; HF12
U11, U12: NC7SB3157; SOT-23-6
U13: L78L06_TO92; TO-92_Molded_Wide_Oval

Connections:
+12V: U13.3 (VI); also elsewhere on the board
BPF: C73.2; also elsewhere on the board
GND: C3.2, C7.2, C70.2, C71.2, C72.2, R8.1, T4.2 (AB), T5.2 (AB), U11.2 (GND), U12.2 (GND), U13.2 (GND); also elsewhere on the board
IF: T4.1 (AA); also elsewhere on the board
unnamed: C1.2, R39.2, U11.6 (S), U12.6 (S)
unnamed: C3.1, C7.1, R8.2, R39.1, R40.1, U11.4 (A), U12.4 (A)
unnamed: C70.1, C71.1, C72.1, R40.2, U11.5 (VCC), U12.5 (VCC), U13.1 (VO)
unnamed: C73.1, T5.1 (AA)
unnamed: T4.3 (SA), T5.3 (SA), U11.1 (B1)
unnamed: T4.4 (SB), T5.5 (SC), U12.3 (B0)
unnamed: T4.5 (SC), T5.4 (SB), U11.3 (B0)
unnamed: T4.6 (SD), T5.6 (SD), U12.1 (B1)
VFO: C1.1; also elsewhere on the board

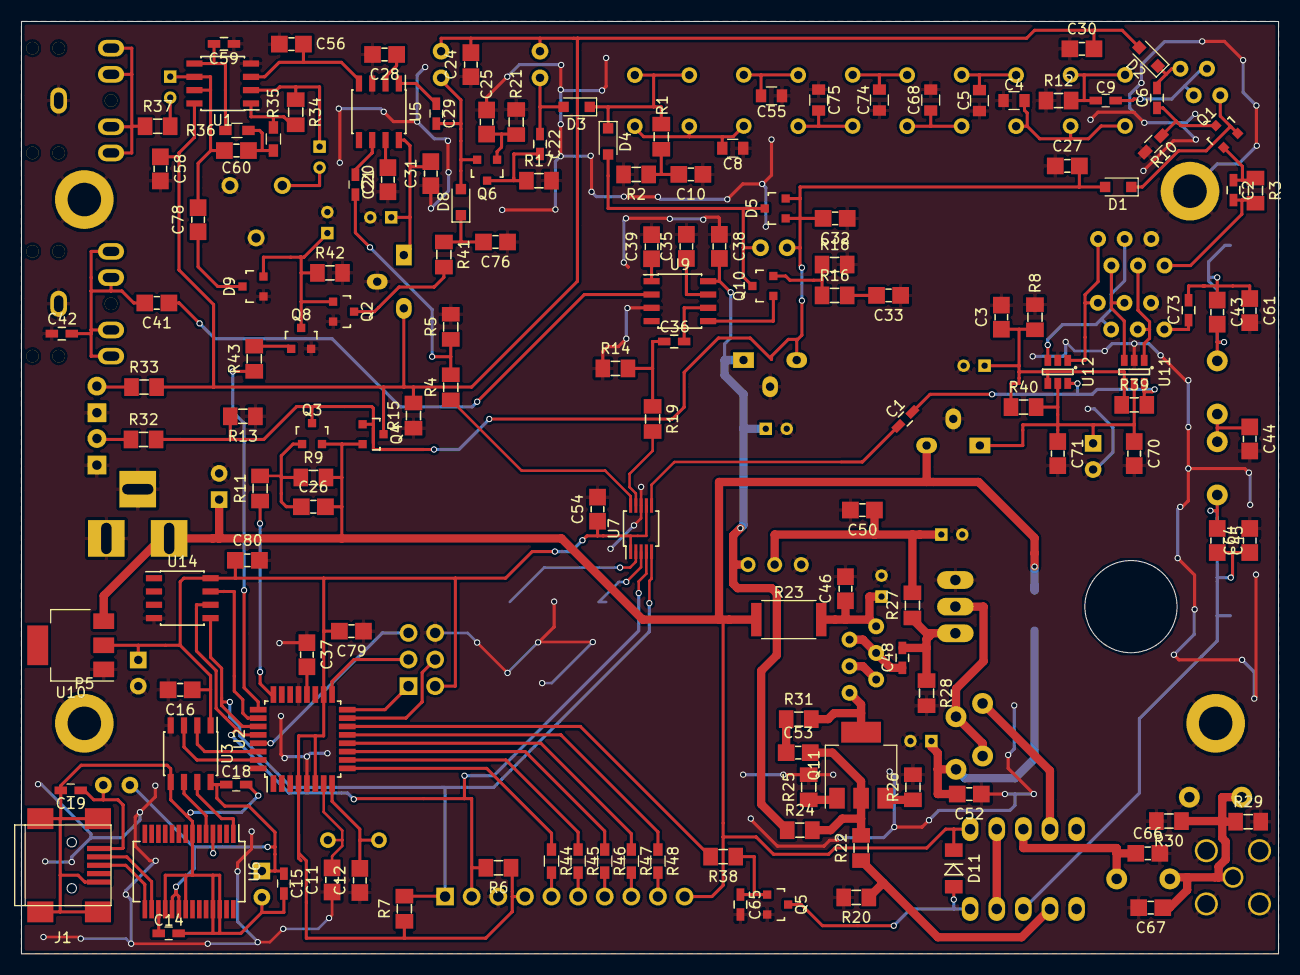
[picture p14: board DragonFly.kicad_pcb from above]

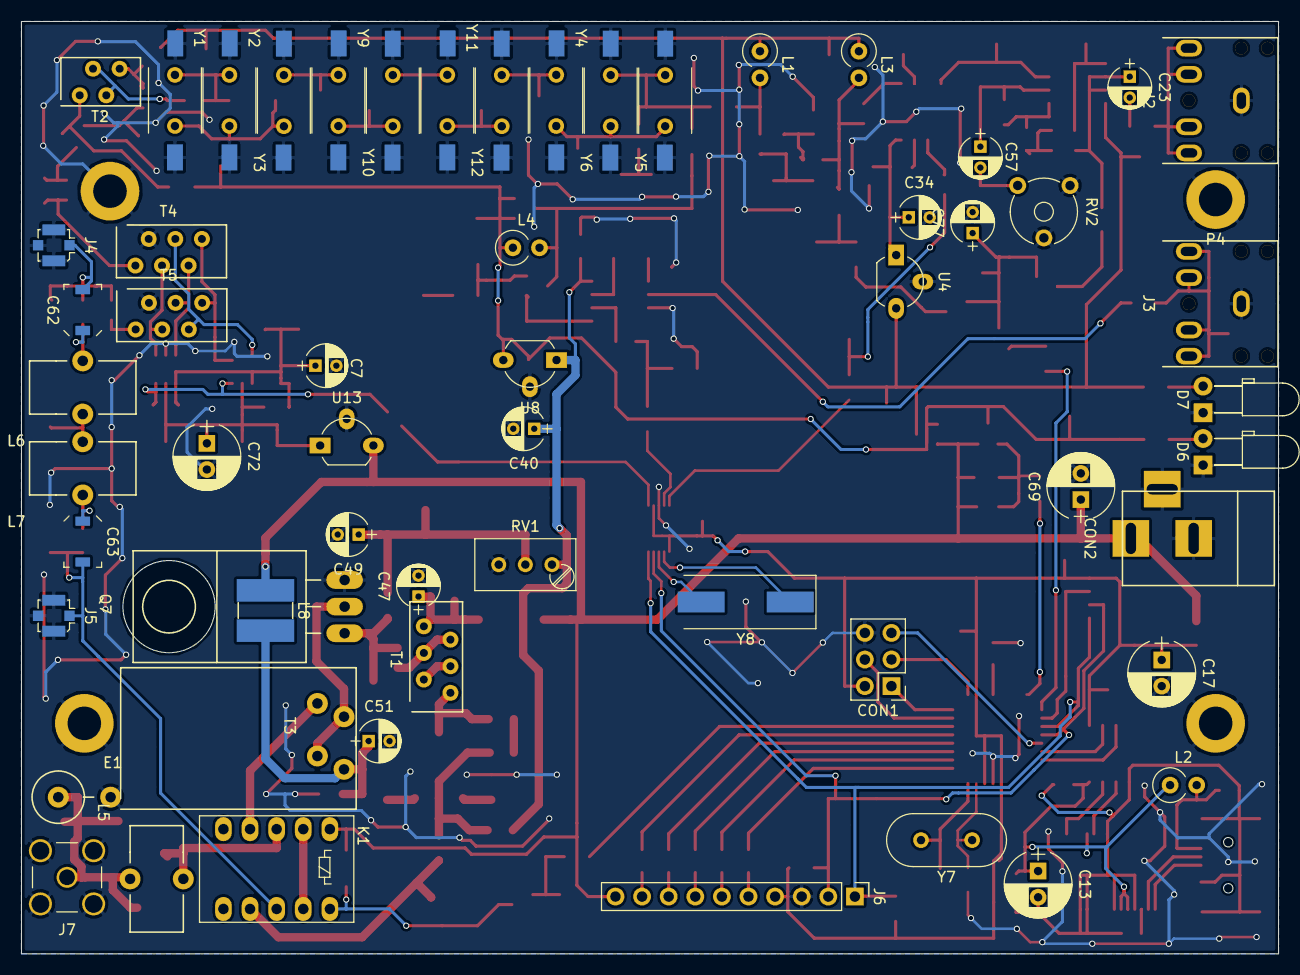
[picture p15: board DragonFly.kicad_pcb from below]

Board: 2 copper layers, 120.0 x 89.0 mm, 204 parts (60 on the bottom side), 129 nets.

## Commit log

2021-08-23 diode mixer on discrete components, begin move to DragonFly libs
    [BPF_PA.sch, DragonFly.kicad_pcb, DragonFly.sch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]
2021-08-23 begin BPF
    [BPF_PA.sch, DragonFly.kicad_pcb, DragonFly.sch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]
2021-08-23 PCB read works, layout BPF
    [BPF_PA.sch, DragonFly.kicad_pcb, DragonFly.sch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]
2021-08-24 PCB progress, QER filter place, PA place
    [BPF_PA.sch, DragonFly.kicad_pcb, DragonFly.sch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]
2021-08-24 PCB progress, IF TX, IF RX, PowerSupply Jack
    [BPF_PA.sch, DragonFly.kicad_pcb, IF_SA612_TX.sch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]
2021-08-25 PCB progress, add digital pin interface, polygon GND, some layout
    [BPF_PA.sch, DragonFly.kicad_pcb, DragonFly.sch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]
2021-08-28 PCB progress, fix MMBFJ310 error
    [BPF_PA.sch, DragonFly.kicad_pcb, DragonFly.sch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]
2021-08-29 UR5FFR Mixer FSA3157
    [BPF_PA.sch, DragonFly.sch, IF.sch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]
2021-08-30 mixer schema is done, pcb progress, fix 78l06 issue
    [BPF_PA.sch, DragonFly.kicad_pcb, DragonFly.sch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]
2021-08-31 denser layout
    [DragonFly.kicad_pcb, DragonFly.sch]
2021-08-31 add AGC circuit
    [BPF_PA.sch, DragonFly.kicad_pcb, DragonFly.sch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]
2021-09-01 add FM24CL16,PCB progress
    [BPF_PA.sch, DragonFly.kicad_pcb, DragonFly.sch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]
2021-09-07 PCB v1.0
    [BPF_PA.sch, DragonFly.kicad_pcb, DragonFly.sch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]
2021-09-08 PCB production
    [BPF_PA.sch, DragonFly.kicad_pcb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]
